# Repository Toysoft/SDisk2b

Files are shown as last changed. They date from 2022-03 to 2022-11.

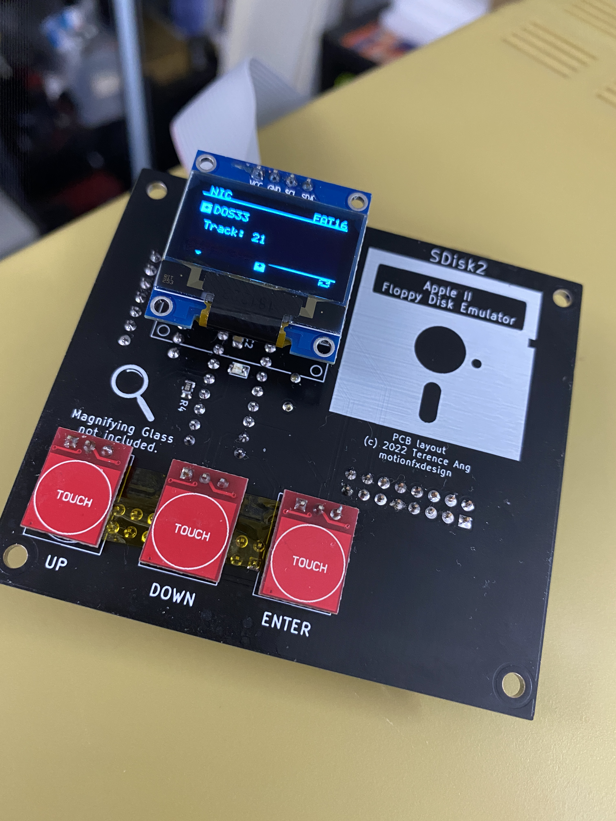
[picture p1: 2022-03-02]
PCB/SDisk2_Simple/Photos/20220302_010335090_iOS.jpg

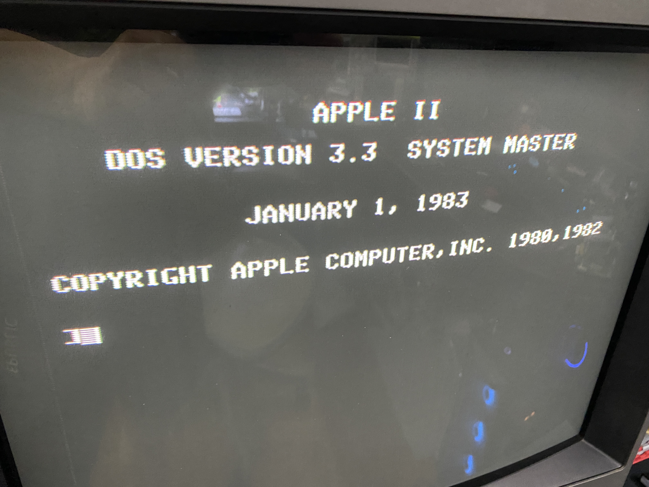
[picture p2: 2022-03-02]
PCB/SDisk2_Simple/Photos/20220302_010408004_iOS.jpg

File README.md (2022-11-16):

# SDisk2 - Simplified

Disk II flopy drive emulator for Apple 2 computers

Objective. an Open Source Disk II floppy Disk emulator that is easy to make.  
See readme in firmware and PCB section for related info.

## Changes

* 27Mhz Xtal.
* OLED only. All LCD and Nokia LCD codes have been removed.
* All Screen rotation code removed.
* Buttons re-arranged

## To-do

1. Better documentaion of the code.

This project will be migrated to an ESP32 based SDISKII.
<https://github.com/terenceang/sdisk2esp>

## Authors

* (c) 2010 Koichi NISHIDA <tulip-house@msf.biglobe.ne.jp>
* (c) 2012 Victor Trucco
* (c) 2012 Fábio Belavenuto
* (c) 2015 Alexandre Suaide
* (c) 2022 Terence Ang

## License

This work is released under the version 3 of the GNU General Public License.

'''NOTE:'''
The current legal status of this code is uncertain.

Fábio and Alexandre have published files with a header that references the version 3 of the GNU General Public License, but it is not clear yet what's the licensing chosen by the original author, Koichi Nishida.

This repository will be updated once the actual licensing info is clarified by the authors.

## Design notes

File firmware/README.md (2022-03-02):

# SDISKII - Simplied version

This package contains a new version of the firmware for the SDISKII with OLED and
buttons to select the NIC image.

Images are saved in the card in NIC format. You can convert DSK to NIC and NIC to DSK
using the utility provided by Nishida in his webpage

     http://tulip-house.ddo.jp/digital/SDISK2/english.html

You can organize your images in subdirectories and you can nest them in as many levels
as you want. In order to save your configuration and keep track of your last mounted
NIC image and directory you need to have the SDISKII.CFG file saved in the top directory
of your SD card. Please use the SDISKII.CFG file provided in this repository.

## FIRMWARE

Note. this fork only support the OLED version, for LCD and Nokia Version, please refer to orignial repo.

  This is for the second version of the SDISK II done by Victor Trucco already with the
  128 x 64 OLED graphical display and USB connection to update the firmware.

  Photos and schematics in the PCB section.

## Formatting the SD card

You can use this version of the firmware with standard SD cards as well as with SDHC
cards. You can format them in FAT16 or FAT32 only. The minimum cluster size is 32kB
(or 64 blocks per cluster). In order to formar a SD card, use the command:

### Windows: (use windows 7 or older. Windows 10 does not work)

    format [letter:] /FS:FAT /A:32K

*you can replace FAT by FAT32.*

### MAC OS/X

    diskutil partitionDisk /dev/[disk name] MBR FAT16 SDISKII 0b
    diskutil umountDisk /deve[disk name]
    newfs_msdos -F 16 -c 64 /dev/[disk name]

*you can replace 16 (FAT16) by 32 (FAT32). The same for the partition scheme.*   
*64 is the number of blocks per cluster and can be larger.*

### Linux

    mkfs.msdos -F 16 -s 64 /dev/[disk name]

*you can replace 16 (FAT16) by 32 (FAT32).*   
*64 is the number of blocks per cluster and can be larger.*

## Selecting NIC image

When there is no disk activity (LED off), press the middle button (ENTER). A list
of NIC files in the current directory as well as the subdirectories, will be created.
Navigate through the list using the LEFT and RIGHT buttons. Use the ENTER button to
select a NIC file or a directory. Directories are shown around [ ].

**Only NIC files are supported.**

## Selecting the delay of the SD card

Standard SD and SDHC cards can differ by a large value in terms of speed. In order
to compensate it a little bit the user can set the delay of the card from 1 (small delays)
to 10 (long delays). The default value is 5 and it looks fine for the cards I testes.
If you get a lot of problems reading NIC file, try to change it a little. I noticed
that ProDOS images are more sensitive to this setting than DOS 3.3 images.

When there is no disk activity (LED off), press the LEFT button. The SDISKII will
prompt you to select the speed of the card. Use the LEFT and RIGHT buttons to
navigate the available speeds and the ENTER (middle) button to select it.

## Swap between two disk images

If you have the SDISKII.CFG file saved in your SD card (see bellow) we keep track of the
previous mounted NIC image. In this case, if you press the RIGHT button we swap the current
mounted NIC with the previous one. This may be useful if you are copying from one image to
another or if you are playing a game that spans over two images.

## Saving the default values and last NIC mounted

In order to save your configurations (SD card speed and last NIC mounted) you need
to copy the file SDISKII.CFG (provided here) in the root directory of your SD card.
If this file is not present every time you turn on the SDISKII the first found NIC
will be mounted and the speed of the SD card will be set to 5.

## Upgrading your SDISKII with this new firmware

In order to upgrade your SDISKII with this new firmware you will need a chip programmer, such
as the MiniPro TL866CS. Remove the ATMEGA328P from your SDISKII, plug it in the programmer.
Open the programmer software, load the firmware.

Check if the fuses are right. The values for the fuses are:

    LFUSE = 0xF7
    HFUSE = 0xF9
    EFUSE = 0xFF

then program your ATMEGA328P with this new firmware. Put it back to the SDISKII and you are set.

*see customisation on how to roll your own version.*

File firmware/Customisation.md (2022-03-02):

# Customisation

## OLED Display - SSD1306

This firmware is made for SSD1306 IIC OLED, you can get them in 0.96 or 1.54 inches size.
pleasse take note of the pinout and make changes accordingly.
pinout configuration for this PCB.

1. VCC
2. GND
3. SCL - PC4
4. SDA - PC5

IIC address is 0x3C

The above can be changed in "config.h"

## SDCARD reader / writer

This PCB uses SDCard reader from LC Studio, this is an old prrt in my bin. It comes with a AM1117-3.3v on board.
You can use any SPI SDcard reader but you will need to convert 5v from the Disk interface to 3.3v for the rest of the circuit.

You will need to disable SD_EJECT signal if your SDcard reader don't support it.

Change
    #define SD_ejected()             bit_is_set(SD_PIN,SD_EJECT)
        to
    #define SD_ejected()             bit_is_clear(SD_PIN,SD_EJECT) // No SD_EJECT support

note. All VCC is 3.3v.

## Buttons

    Buttons
    Enter   - PD6
    Down    - PD7
    UP      - PB5

I am uaing TP223, button press is active high.
So button detection is.

    // Active high (using TP223)
    #define enter_is_pressed() bit_is_set(ENTER_PORT,ENTER_BIT)
    #define down_is_pressed()  bit_is_set(DOWN_PORT,DOWN_BIT)
    #define up_is_pressed()    bit_is_set(UP_PORT,UP_BIT)

Change bit_is_set to bit_is_celar for active low switches. e.g tact switch with pull up resistor.

## LED

    LED is on PB4

## Compiling the firmware

Use avr-gcc either on windows, mac or linux.
see avr-gcc website on how to set up the toolchain.

With the above info, you should be able to make your own SDISK2 version, please post your questions in the discussion page and I will try to help you with it. Thank you.

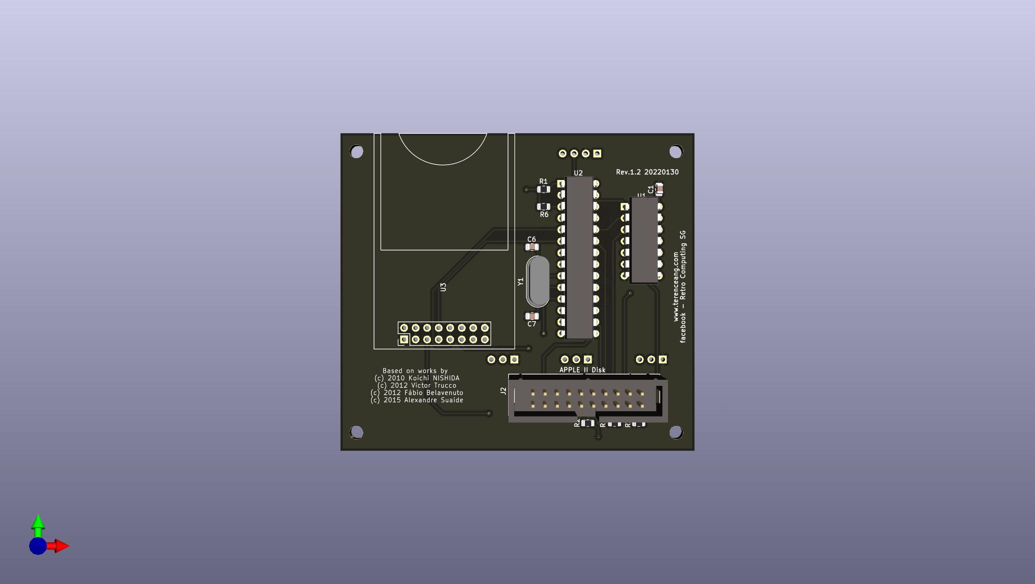
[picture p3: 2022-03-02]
PCB/SDisk2_Simple/Photos/SDisk2_Simple front.jpg

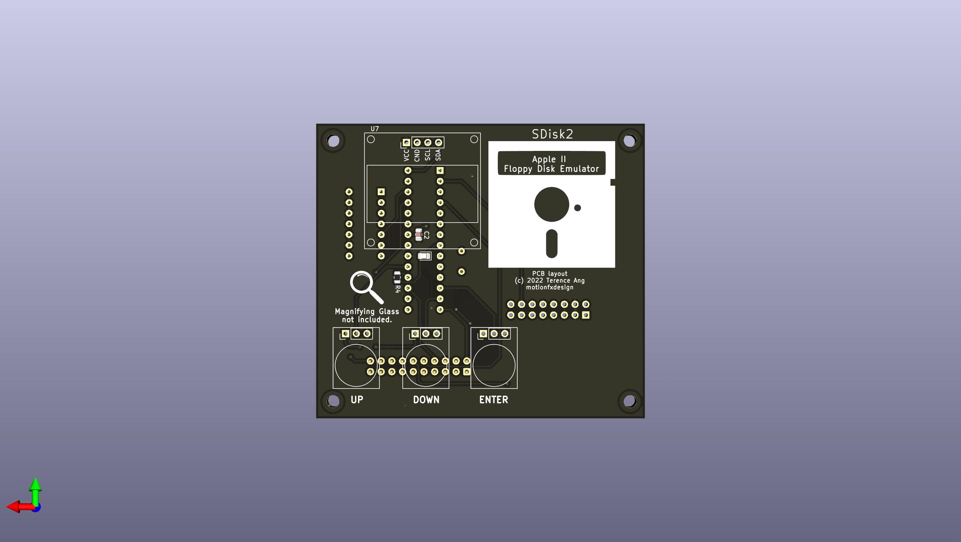
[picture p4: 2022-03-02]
PCB/SDisk2_Simple/Photos/SDisk2_Simple_back.jpg

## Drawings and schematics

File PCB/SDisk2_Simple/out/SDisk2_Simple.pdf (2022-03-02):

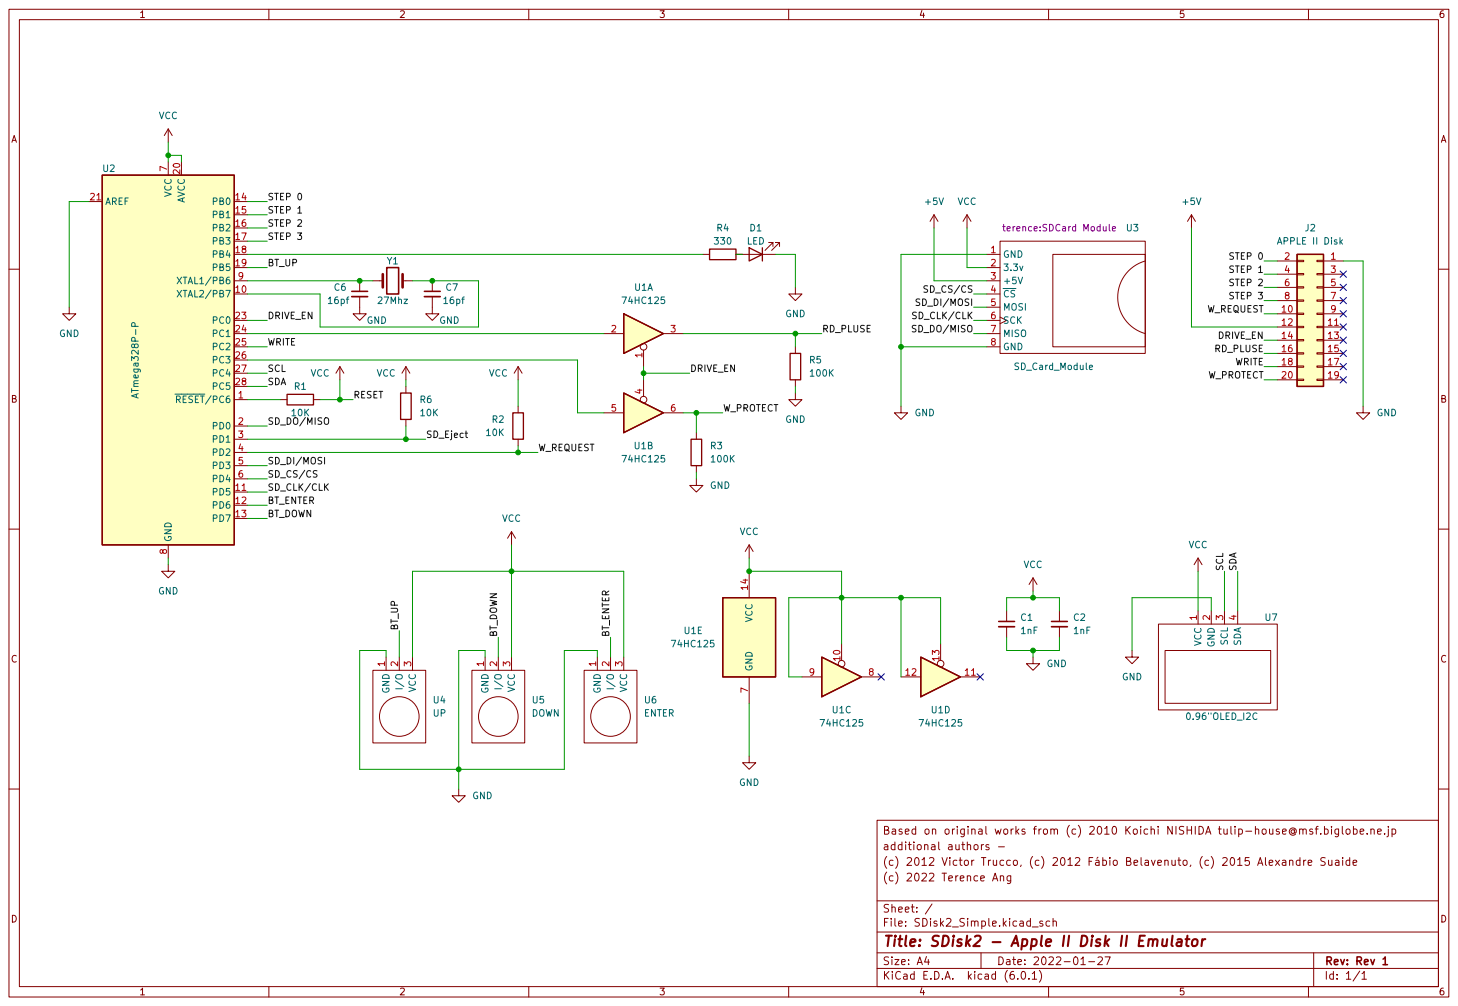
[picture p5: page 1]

J2 APPLE II Disk GND

additional authors - Based on original works from (c) 2010 Koichi NISHIDA tulip-house@msf.biglobe.ne.jp VCC 14 GND

3 U6 ENTER GND GND GND
74HC125 GND

File: SDisk2_Simple.kicad_sch Sheet: / (c) 2022 Terence Ang

Id: 1/1 Title: SDisk2 - Apple II Disk II Emulator

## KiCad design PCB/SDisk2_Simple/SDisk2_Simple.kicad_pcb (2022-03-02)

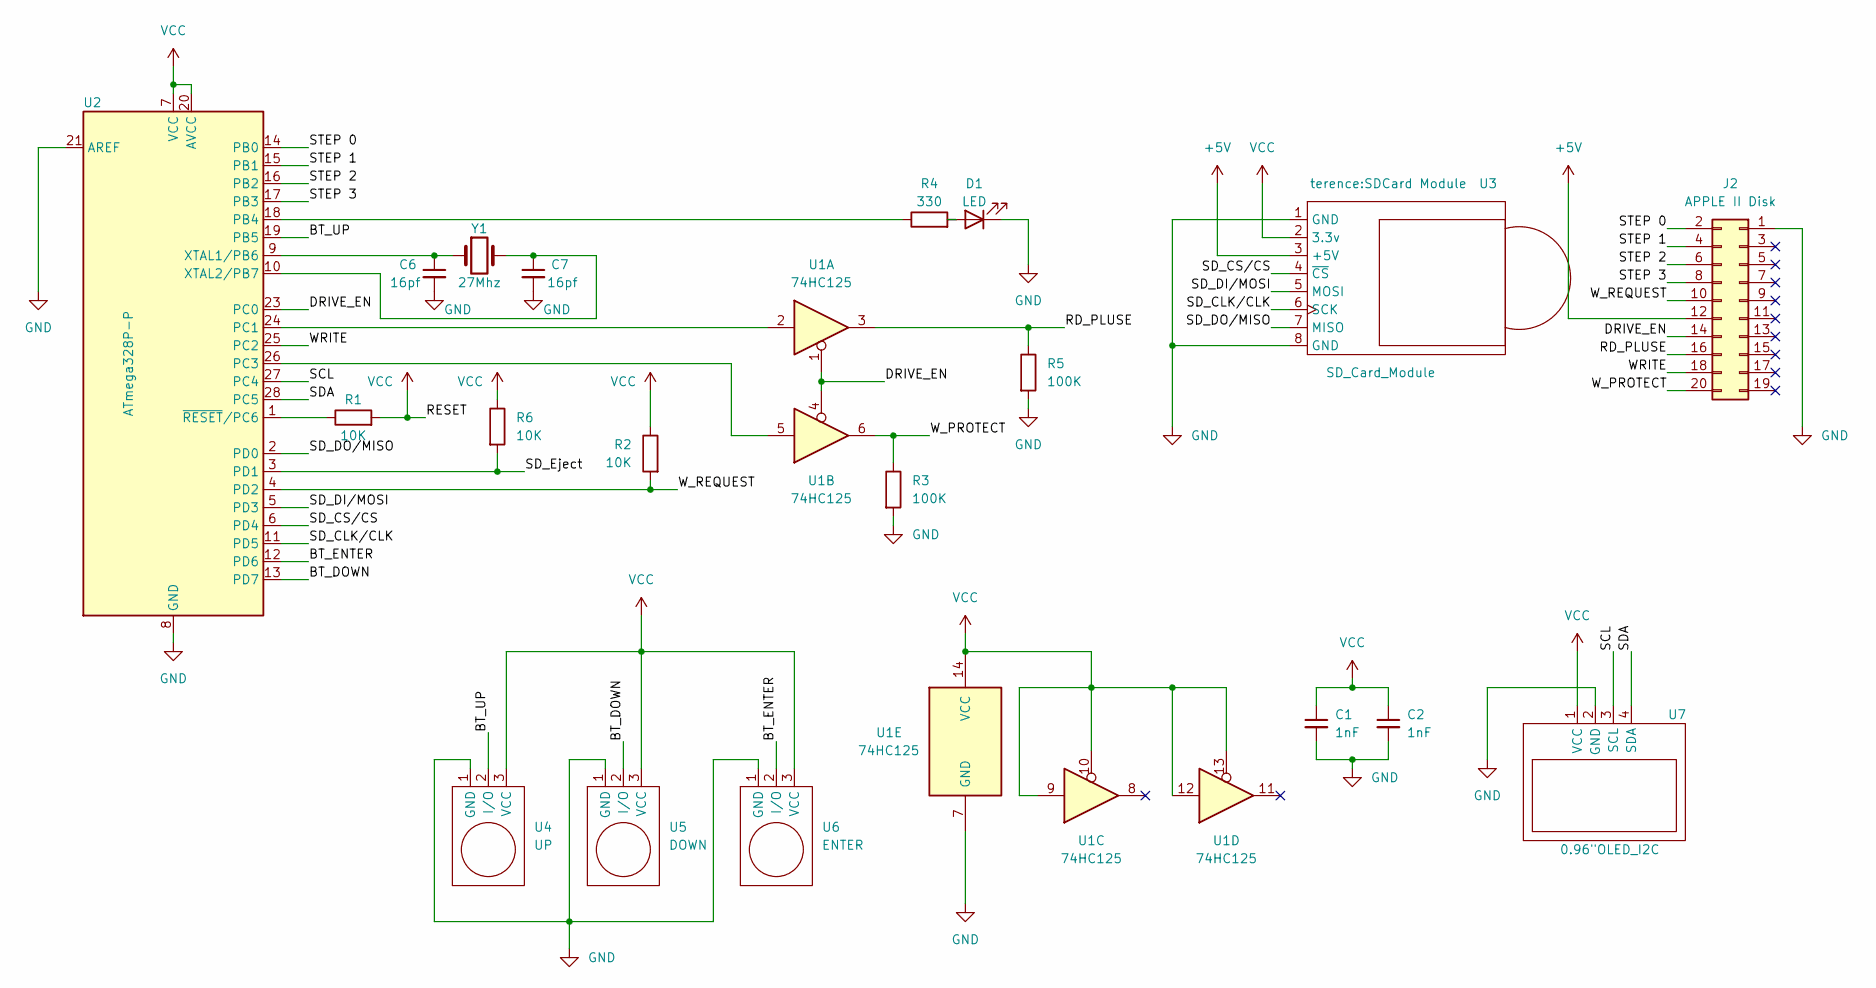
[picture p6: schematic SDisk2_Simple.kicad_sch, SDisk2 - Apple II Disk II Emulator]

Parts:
C1, C2: 1nF; C_0805_2012Metric
C6, C7: 16pf; C_0805_2012Metric
D1: LED; LED_0805_2012Metric
J2: APPLE II Disk; IDC-Header_2x10_P2.54mm_Vertical
R1, R2, R6: 10K; R_0805_2012Metric
R3, R5: 100K; R_0805_2012Metric
R4: 330; R_0805_2012Metric
U1: 74HC125; DIP-14_W7.62mm
U2: ATmega328P-P; DIP-28_W7.62mm
U3: SD_Card_Module; SDCard Module
U4: UP; TP223
U5: DOWN; TP223
U6: ENTER; TP223
U7: 0.96"OLED_I2C; 0.96OLED I2C
Y1: 27Mhz; Crystal_HC49-U_Vertical

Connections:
+5V: J2.12, U3.3 (+5V)
/BT_DOWN: U2.13 (PD7), U5.2 (I/O)
/BT_ENTER: U2.12 (PD6), U6.2 (I/O)
/BT_UP: U2.19 (PB5), U4.2 (I/O)
/DRIVE_EN: J2.14, U1.1, U1.4, U2.23 (PC0)
/RD_PLUSE: J2.16, R5.1, U1.3
/SCL: U2.27 (PC4), U7.3 (SCL)
/SDA: U2.28 (PC5), U7.4 (SDA)
/SD_CLK/CLK: U2.11 (PD5), U3.6 (SCK)
/SD_CS/CS: U2.6 (PD4), U3.4 (~CS)
/SD_DI/MOSI: U2.5 (PD3), U3.5 (MOSI)
/SD_DO/MISO: U2.2 (PD0), U3.7 (MISO)
/SD_Eject: R6.2, U2.3 (PD1)
/STEP 0: J2.2, U2.14 (PB0)
/STEP 1: J2.4, U2.15 (PB1)
/STEP 2: J2.6, U2.16 (PB2)
/STEP 3: J2.8, U2.17 (PB3)
/WRITE: J2.18, U2.25 (PC2)
/W_PROTECT: J2.20, R3.1, U1.6
/W_REQUEST: J2.10, R2.2, U2.4 (PD2)
GND: C1.2, C2.2, C6.2, C7.2, D1.1 (K), J2.1, R3.2, R5.2, U1.7 (GND), U2.8 (GND), U2.21 (AREF), U2.22 (GND), U3.1 (GND), U3.8 (GND), U4.1 (GND), U5.1 (GND), U6.1 (GND), U7.2 (GND)
unnamed: C6.1, U2.9 (XTAL1/PB6), Y1.1
unnamed: C7.1, U2.10 (XTAL2/PB7), Y1.2
unnamed: D1.2 (A), R4.2
unnamed: R1.1, U2.1 (~RESET/PC6)
unnamed: R4.1, U2.18 (PB4)
unnamed: U1.2, U2.24 (PC1)
unnamed: U1.5, U2.26 (PC3)
VCC: C1.1, C2.1, R1.2, R2.1, R6.1, U1.9, U1.10, U1.12, U1.13, U1.14 (VCC), U2.7 (VCC), U2.20 (AVCC), U3.2 (3.3v), U4.3 (VCC), U5.3 (VCC), U6.3 (VCC), U7.1 (VCC)

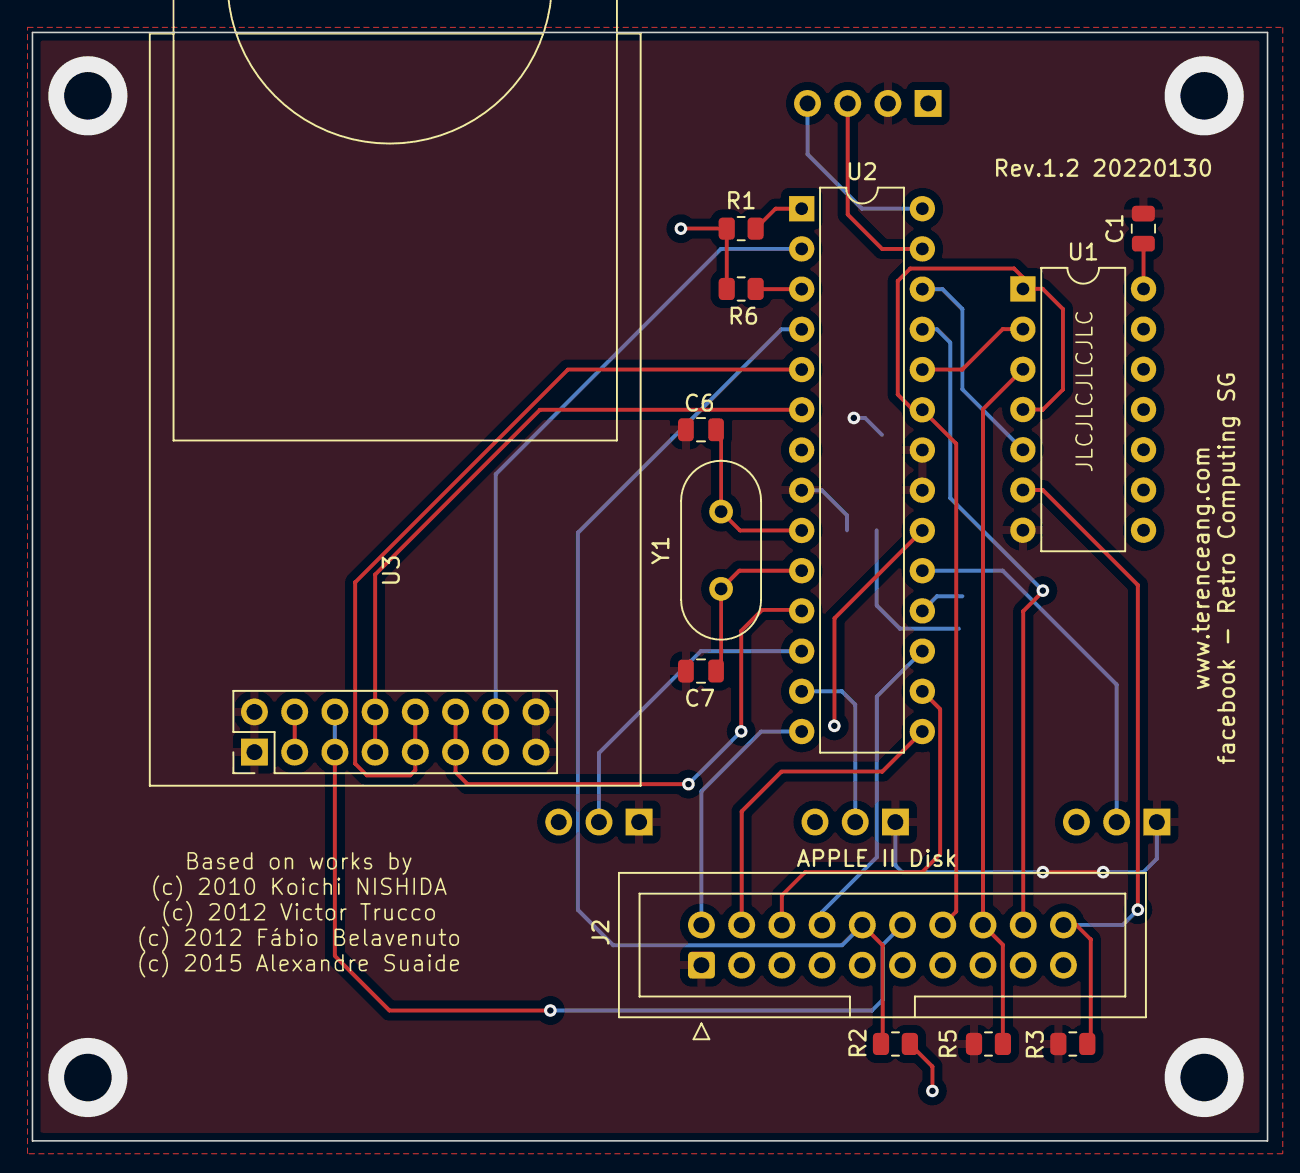
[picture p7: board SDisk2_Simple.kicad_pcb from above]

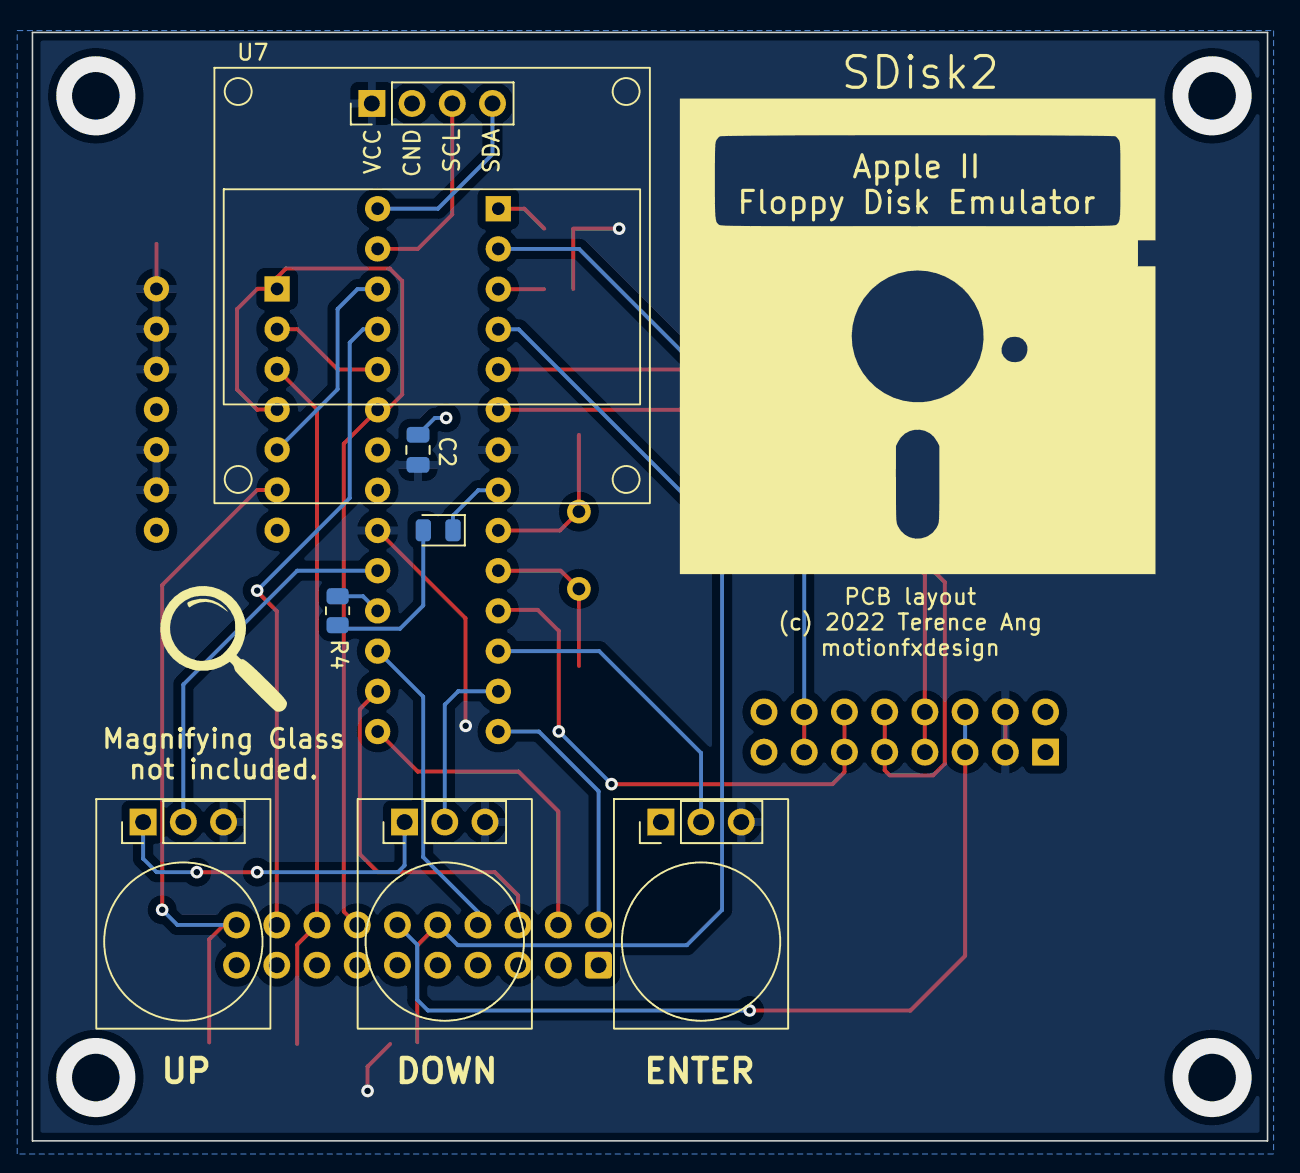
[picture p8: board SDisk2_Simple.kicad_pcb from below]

Board: 2 copper layers, 78.0 x 70.0 mm, 20 parts (7 on the bottom side), 29 nets.

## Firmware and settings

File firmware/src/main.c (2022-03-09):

/*------------------------------------
SDISK II LCD Firmware
2010.11.11 by Koichi Nishida
2012.01.26 by Fábio Belavenuto
2015.07.02 by Alexandre Suaide
-------------------------------------
*/

/*
2015.07.02 by Alexandre Suaide
Added support for SDHC cards and subdirectories
Removed DSK to NIC conversion
FAT16 and FAT32 disks should have at least 64 blocks per cluster
*/

/*
2012.01.26 by Fábio Belavenuto
Added support for image exchange using a button added in the Brazilian version by Victor Trucco
Added support for a 16x2 LCD
*/

/*
This is a part of the firmware for DISK II emulator by Nishida Radio.
Copyright (C) 2010 Koichi NISHIDA
email to Koichi NISHIDA: tulip-house@msf.biglobe.ne.jp
This program is free software; you can redistribute it and/or modify it
under the terms of the GNU General Public License as published by
the Free Software Foundation; either version 3 of the License.
This program is distributed in the hope that it will be useful,
but WITHOUT ANY WARRANTY; without even the implied warranty of
MERCHANTABILITY or FITNESS FOR A PARTICULAR PURPOSE.
See the GNU General Public License for more details.
You should have received a copy of the GNU General Public License
along with this program. If not, see <http://www.gnu.org/licenses/>.
*/

#include "main.h"

#define BUF_NUM 4 // originalmente era 5. testando por conta de um possivel overflow de memoria na sdisk nova com oled
unsigned char writeData[BUF_NUM][350];
unsigned char sectors[BUF_NUM], tracks[BUF_NUM];
unsigned char buffNum;
unsigned char *writePtr;
unsigned char flip_buttons;

#define DEBOUNCE 200

#define MAXFILES 200
unsigned char *files_id;
int nfiles = 0;
int selected_file_id = 0;
int id_of_config_file = -1;

#define FAT_NIC_ELEMS 10
#define NIC_FILE_SIZE 280
unsigned long fatNic[FAT_NIC_ELEMS];

// DISK II status
unsigned char ph_track; // 0 - 139
unsigned char sector;	// 0 - 15
unsigned short bitbyte; // 0 - (8*512-1)
unsigned char prepare;
unsigned char readPulse;
unsigned char inited;
unsigned char magState;
unsigned char protect;
unsigned char formatting;
const unsigned char volume = 0xfe;

unsigned char trk;
unsigned short long_sector;
unsigned short long_cluster;
unsigned long ft;
unsigned char old_trk;

/*Error codes
1 - Can not put SD Card on idle state
2 - Can not make SD Card initialization
3 - Can not init FAT
4 - Partition type not supported (only FAT16 and FAT32)
5 - Cluster size smaller than minimum to keep buffer
*/

/*                               012345678901234567890*/
PROGMEM const char SPLASH1[] = "      SDISK ][";
PROGMEM const char VERSION[] = "  version " VER " " YEAR;
PROGMEM const char NIC[] = " NIC                 ";
PROGMEM const char SETUP[] = " SETUP               ";
PROGMEM const char EMP[] = "                     ";
PROGMEM const char SET1[] = " Set SD delay        ";
PROGMEM const char SET2[] = " Set contrast        ";
PROGMEM const char SET3[] = " Rotate display      ";
PROGMEM const char VALUE[] = " Value: ";
PROGMEM const char CONT[] = " LCD CONTRAST        ";
PROGMEM const char DLAY[] = " SD SELECT DELAY     ";
PROGMEM const char TRAK[] = "Track: ";
PROGMEM const char MSG7[] = " SELECT NIC          ";
PROGMEM const char MSGC[] = " Building list";
PROGMEM const char MSG8[] = " Nothing found here! ";
PROGMEM const char MSGD[] = " Sorting files ...   ";
PROGMEM const char MSHC[] = "SDHC card     ";
PROGMEM const char MSSD[] = "Normal SD card";
PROGMEM const char ERR[] = "E R R O R";
PROGMEM const char ERM1[] = "SD can't idle ";
PROGMEM const char ERM2[] = "SD can't init ";
PROGMEM const char ERM3[] = "Boot sector   ";
PROGMEM const char ERM4[] = "Not FAT16/32  ";
PROGMEM const char ERM5[] = "Cluster < 32kB";
PROGMEM const char ERM6[] = "Missing MBR   ";
PROGMEM const char ERM7[] = "SD Block ERROR";
PROGMEM const char ERMC[] = "Code: ";
PROGMEM const char PART[] = "Type: ";
PROGMEM const char FAT3[] = "FAT32";
PROGMEM const char FAT1[] = "FAT16";
PROGMEM const char SDOUT[] = "No SD inserted";
#define TRX 12
#define TRY 4

PROGMEM const char CFG[] = "SDISKII CFG";

// a table for head stepper motor movement
PROGMEM const prog_uchar stepper_table[4] = {0x0f, 0xed, 0x03, 0x21};

int main(void)
{
	static unsigned char oldStp = 0, stp;
	init(1);
	old_trk = 255;
	while (1)
	{
		verify_status();
		if (diskII_disable())
		{
			SD_led_off();
		}
		else
		{
			SD_led_on();
			stp = (PINB & 0b00001111);
			if (stp != oldStp)
			{
				oldStp = stp;
				unsigned char ofs = ((stp == 0b00001000) ? 2 : ((stp == 0b00000100) ? 4 : ((stp == 0b00000010) ? 6 : ((stp == 0b00000001) ? 0 : 0xff))));
				if (ofs != 0xff)
				{
					ofs = ((ofs + ph_track) & 7);
					unsigned char bt = pgm_read_byte_near(stepper_table + (ofs >> 1));
					oldStp = stp;
					if (ofs & 1)
						bt &= 0x0f;
					else
						bt >>= 4;
					ph_track += ((bt & 0x08) ? (0xf8 | bt) : bt);
					if (ph_track > 196)
						ph_track = 0;
					if (ph_track > 139)
						ph_track = 139;
				}
			}

			if (inited && prepare)
			{
				cli();
				sector = ((sector + 1) & 0xf);
				{
					trk = (ph_track >> 2);
					long_sector = (unsigned short)trk * 16 + sector;
					long_cluster = long_sector >> FAT_sectorsPerClusterBitShift;
					ft = fatNic[long_cluster];
					if (trk != old_trk)
					{
						old_trk = trk;
						ssd1306_gotoxy(TRX, TRY);
						ssd1306_put_p(TRAK);
						if (trk < 10)
							ssd1306_string(" ");
						ssd1306_put_i((unsigned int)trk);
					}

					if (((sectors[0] == sector) && (tracks[0] == trk)) || ((sectors[1] == sector) && (tracks[1] == trk)) ||
						((sectors[2] == sector) && (tracks[2] == trk)) || ((sectors[3] == sector) && (tracks[3] == trk)))
						writeBackSub();

					// Timing is an issue here. This is the reason I copied explicitly the conversion from cluster to block
					// instead of using getCluster() method. I also did bit shift instead of multiplications to make it faster.
					// even inline function is not fast enough.
					// SD_CMD17Special is also faster than the regular SD_sendCommand method.
					SD_CMD17Special((((ft - 2) << FAT_sectorsPerClusterBitShift) + FAT_firstDataSector) + (long_sector & (FAT_sectorsPerCluster - 1)));
					bitbyte = 0;
					prepare = 0;
				}

				sei();
			}
		}
	}
}

void display_sd_ejected()
{

	ssd1306_clear();
	ssd1306_gotoxy(37, 2);
	ssd1306_put_p(ERR);
	ssd1306_gotoxy(22, 4);
	ssd1306_put_p(SDOUT);

	do
	{
	} while (SD_ejected());
	return;
}

char init_sd(char splash)
{
	id_of_config_file = -1;
	SPI_slow();
	SD_select_card();
	unsigned char ok;
	if (SD_ejected())
	{
		display_sd_ejected();
		return 0;
	}

	buffer = &writeData[0][0];
	ok = SD_init();

	if (!ok)
	{
		ssd1306_clear();
		ssd1306_gotoxy(37, 2);
		ssd1306_put_p(ERR);
		ssd1306_gotoxy(22, 4);
		if (errorCode == 1)
			ssd1306_put_p(ERM1);
		else if (errorCode == 2)
			ssd1306_put_p(ERM2);
		else if (errorCode == 3)
			ssd1306_put_p(ERM3);
		else if (errorCode == 4)
			ssd1306_put_p(ERM4);
		else if (errorCode == 5)
			ssd1306_put_p(ERM5);
		else if (errorCode == 6)
			ssd1306_put_p(ERM6);
		else if (errorCode == 7)
			ssd1306_put_p(ERM7);
		else
		{
			ssd1306_put_p(ERMC);
			ssd1306_put_i(errorCode);
		}
		inited = 0;
		while (!SD_ejected())
		{
		};
		return 0;
	}

	if (splash)
	{
		ssd1306_clear();
		ssd1306_gotoxy(0, 2);

		if (SD_version == SD_RAW_SPEC_SDHC)
			ssd1306_put_p(MSHC);
		else
			ssd1306_put_p(MSSD);

		SD_select_card();
		_delay_ms(1000);
	}

	ok = FAT_init();
	if (!ok)
	{
		ssd1306_clear();
		ssd1306_gotoxy(37, 2);
		ssd1306_put_p(ERR);
		ssd1306_gotoxy(22, 4);

		if (errorCode == 1)
			ssd1306_put_p(ERM1);
		else if (errorCode == 2)
			ssd1306_put_p(ERM2);
		else if (errorCode == 3)
			ssd1306_put_p(ERM3);
		else if (errorCode == 4)
			ssd1306_put_p(ERM4);
		else if (errorCode == 5)
			ssd1306_put_p(ERM5);
		else if (errorCode == 6)
			ssd1306_put_p(ERM6);
		else if (errorCode == 7)
			ssd1306_put_p(ERM7);
		else
		{
			ssd1306_put_p(ERMC);
			ssd1306_put_i(errorCode);
		}
		inited = 0;
		while (!SD_ejected())
		{
		};
		return 0;
	}

	if ((FAT_bytesPerSector * FAT_sectorsPerCluster / 1024) < (NIC_FILE_SIZE / FAT_NIC_ELEMS))
	{
		errorCode = 5;
		ssd1306_clear();
		ssd1306_gotoxy(37, 2);
		ssd1306_put_p(ERR);
		ssd1306_gotoxy(22, 4);
		ssd1306_put_p(ERM5);

		inited = 0;
		while (!SD_ejected())
		{
		};
		return 0;
	}

	if (splash)
	{
		ssd1306_gotoxy(0, 4);

		ssd1306_put_p(PART);
		if (FAT_partitionType == PARTITION_TYPE_FAT16)
			ssd1306_put_p(FAT1);
		else
			ssd1306_put_p(FAT3);

		_delay_ms(1000);
		// SD_select_card();
	}
	SD_select_card();
	buffClear();
	SPI_fast();
	return 1;
}

void init(char splash)
{
	// configuracao das portas do microcontrolador

	DDRB = 0;
	DDRC = 0;
	DDRD = 0;

	PORTB = 0;
	PORTC = 0;
	PORTD = 0;

	// configuração do LED
	set_bit(SD_LED_PORTD, SD_LED);
	set_bit(SD_LED_PORT, SD_LED); // LED ligado

	// configuração da interface com o Apple
	set_bit(DDRC, 1);
	set_bit(DDRC, 3);
	set_bit(PORTC, 1);

	// configuração da interrupção de tempo
	OCR0A = 0;
	TCCR0A = 0;
	TCCR0B = 1;

	// configuração da interrupção int0
	MCUCR = 0b00000010;
	EICRA = 0b00000010;

	sector = 0;
	inited = 0;
	readPulse = 0;
	protect = 0;
	bitbyte = 0;
	magState = 0;
	prepare = 1;
	ph_track = 0;
	buffNum = 0;
	formatting = 0;
	writePtr = &(writeData[buffNum][0]);

	if (splash)
	{
		ssd1306_init();
		ssd1306_clear();
		ssd1306_gotoxy(0, 0);
		logo();
		ssd1306_gotoxy(13, 6);
		ssd1306_put_p(SPLASH1);
		ssd1306_gotoxy(7, 7);
		ssd1306_put_p(VERSION);
		_delay_ms(1500);
	}
}

void verify_status(void)
{
	unsigned int i;
	configButtons();
	if (SD_ejected())
	{
		for (i = 0; i != 0xFF; i++)
			if (!SD_ejected())
				return;
		TIMSK0 &= ~(1 << TOIE0);
		EIMSK &= ~(1 << INT0);
		inited = 0;
		prepare = 0;
		display_sd_ejected();
		return;
	}
	else if (diskII_disable() && (enter_is_pressed() || down_is_pressed() || up_is_pressed()))
	{
		if (enter_is_pressed()) // drive disabled
		{
			unsigned char flg = 1;
			for (i = 0; i != 100; i++)
				if (!enter_is_pressed())
					flg = 0;
			if (flg)
			{
				while (enter_is_pressed())
					; // enter button pushed !
				cli();
				select_nic();
				if (SD_ejected())
					return;
				if (inited)
				{
					TIMSK0 |= (1 << TOIE0);
					EIMSK |= (1 << INT0);
				}
				sei();
			}
			return;
		}

		else if (down_is_pressed()) // setup
		{
			unsigned char flg = 1;
			for (i = 0; i != 100; i++)
				if (!down_is_pressed())
					flg = 0;
			if (flg)
			{
				while (down_is_pressed())
					; // enter button pushed !
				cli();
				setup();
				if (SD_ejected())
					return;
				find_previous_nic();
				if (inited)
				{
					TIMSK0 |= (1 << TOIE0);
					EIMSK |= (1 << INT0);
				}
				sei();
			}
			return;
		}
		else if (up_is_pressed())
		{
			unsigned char flg = 1;
			for (i = 0; i != 100; i++)
				if (!up_is_pressed())
					flg = 0;
			if (flg)
			{
				while (up_is_pressed())
					; // botao ainda apertado
				cli();
				swap_nic();
				if (SD_ejected())
					return;
				if (inited)
				{
					TIMSK0 |= (1 << TOIE0);
					EIMSK |= (1 << INT0);
				}
				sei();
			}
		}
	}
	else if (!inited) // if not initialized
	{
		for (i = 0; i != 0xFF; i++)
			if (SD_ejected())
				return;
		cli();
		if (init_sd(1))
			find_previous_nic();
		if (inited)
		{

			TIMSK0 |= (1 << TOIE0);
			EIMSK |= (1 << INT0);
		}
		sei();
	}
}

// Contrast Page
void set_contrast()
{
	unsigned char contrast = 0XAF;
	if (id_of_config_file != -1)
	{
		cd(0);
		buffer = &writeData[0][0];
		buffClear();
		lastBlockRead = 0;
		struct dir_Structure *config_file = getFile(id_of_config_file);
		unsigned long cluster;

		if (FAT_partitionType == PARTITION_TYPE_FAT32)
			cluster = (unsigned long)config_file->firstClusterHI << 16 | (unsigned long)config_file->firstClusterLO;
		else
			cluster = (unsigned long)config_file->firstClusterLO;

		SD_readSingleBlock(getSector(cluster));
		struct Sdisk_config_structure *config = (struct Sdisk_config_structure *)buffer;
		if (config->checksum == CHECKSUM_CONFIG)
		{
			contrast = config->oled_contrast;
		}
	}
	ssd1306_clear();
	ssd1306_gotoxy(0, 0);
	ssd1306_underline();
	ssd1306_put_p(CONT);
	ssd1306_underline();
	icons(3, 4, 5); // 5-enter, 4-down, 3-up

	ssd1306_gotoxy(0, 2);
	ssd1306_put_p(VALUE);
	ssd1306_put_i(contrast);

	unsigned char old_contrast = contrast;
	unsigned char original_contrast = contrast;
	while (1)
	{
		configButtons();
		if (contrast != old_contrast)
		{
			ssd1306_gotoxy(0, 2);
			ssd1306_put_p(VALUE);
			ssd1306_put_i(contrast);
			ssd1306_put_p(PSTR(" "));
			old_contrast = contrast;
		}

		if (SD_ejected())
			return; // card is removed
		if (down_is_pressed())
		{
			while (down_is_pressed())
			{
			}
			_delay_ms(DEBOUNCE);

			contrast--;
			if (contrast < MIN_CONTRAST)
				contrast = MIN_CONTRAST;
			else
			{
				oled_contrast = contrast;
				ssd1306_contrast(oled_contrast);
			}
		}
		if (up_is_pressed())
		{
			while (up_is_pressed())
			{
			}
			_delay_ms(DEBOUNCE);

			contrast++;
			if (contrast > MAX_CONTRAST)
				contrast = MAX_CONTRAST;
			else
			{
				oled_contrast = contrast;
				ssd1306_contrast(oled_contrast);
			}
		}
		if (enter_is_pressed())
		{
			while (enter_is_pressed())
			{
			}
			_delay_ms(DEBOUNCE);
			if (contrast != original_contrast)
			{
				oled_contrast = contrast;
				ssd1306_contrast(oled_contrast);
				SD_select_card();
				if (id_of_config_file != -1)
				{
					cd(0);
					buffer = &writeData[0][0];
					buffClear();
					lastBlockRead = 0;
					struct dir_Structure *config_file = getFile(id_of_config_file);
					unsigned long cluster;

					if (FAT_partitionType == PARTITION_TYPE_FAT32)
						cluster = (unsigned long)config_file->firstClusterHI << 16 | (unsigned long)config_file->firstClusterLO;
					else
						cluster = (unsigned long)config_file->firstClusterLO;

					SD_readSingleBlock(getSector(cluster));
					struct Sdisk_config_structure *config = (struct Sdisk_config_structure *)buffer;
					if (config->checksum == CHECKSUM_CONFIG)
					{
						config->oled_contrast = contrast;
						SD_writeSingleBlock(getSector(cluster));
					}
				}
			}
			return;
		}
	}
	return;
}

// Setup Page
void setup()
{
	ssd1306_clear();
	ssd1306_gotoxy(0, 0);
	ssd1306_underline();
	ssd1306_put_p(SETUP);
	ssd1306_underline();

	icons(3, 4, 5); // 5-enter, 4-down, 3-up

	unsigned char option = 1;
	ssd1306_gotoxy(0, 2);
	ssd1306_inverse();
	ssd1306_put_p(SET1); // set speed
	ssd1306_inverse();
	ssd1306_gotoxy(0, 3);
	ssd1306_put_p(SET2); // set contrast

#define MAX_SET 2 // number of item

	while (1)
	{
		configButtons();
		if (down_is_pressed())
		{
			while (down_is_pressed())
			{
			}
			_delay_ms(DEBOUNCE);

			option++;
			if (option > MAX_SET)
				option = MAX_SET;
			else
			{
				if (option == 1)
					ssd1306_inverse();
				ssd1306_gotoxy(0, 2);
				ssd1306_put_p(SET1);
				if (option == 1)
					ssd1306_inverse();

				if (option == 2)
					ssd1306_inverse();
				ssd1306_gotoxy(0, 3);
				ssd1306_put_p(SET2);
				if (option == 2)
					ssd1306_inverse();
			}
		}
		if (up_is_pressed())
		{
			while (up_is_pressed())
			{
			}
			_delay_ms(DEBOUNCE);

			option--;
			if (option < 1)
				option = 1;
			else
			{
				if (option == 1)
					ssd1306_inverse();
				ssd1306_gotoxy(0, 2);
				ssd1306_put_p(SET1);
				if (option == 1)
					ssd1306_inverse();

				if (option == 2)
					ssd1306_inverse();
				ssd1306_gotoxy(0, 3);
				ssd1306_put_p(SET2);
				if (option == 2)
					ssd1306_inverse();
			}
		}
		if (enter_is_pressed())
		{
			while (enter_is_pressed())
			{
			}
			_delay_ms(DEBOUNCE);
			if (option == 1)
				set_speed();
			if (option == 2)
				set_contrast();
			return;
		}
	}
}

void icons(unsigned char i1, unsigned char i2, unsigned char i3)
{

#define IC_LINE 7
#define IC_1 0
#define IC_2 58
#define IC_3 115

	ssd1306_gotoxy(IC_1, IC_LINE);
	ssd1306_overline();
	ssd1306_put_p(EMP);
	ssd1306_gotoxy(IC_1, IC_LINE);
	ssd1306_icon(i1);
	ssd1306_gotoxy(IC_2, IC_LINE);
	ssd1306_icon(i2);
	ssd1306_gotoxy(IC_3, IC_LINE);
	ssd1306_icon(i3);
	ssd1306_overline();
}

void set_speed()
{
	ssd1306_clear();
	ssd1306_gotoxy(0, 0);
	ssd1306_underline();
	ssd1306_put_p(DLAY);
	ssd1306_underline();
	icons(3, 5, 4); // 5-setup, 4-Disk, 3-last Disk
	ssd1306_gotoxy(0, 3);
	ssd1306_put_p(VALUE);
	ssd1306_put_i(SD_speed);

	unsigned char old_speed = SD_speed;
	unsigned char original_speed = SD_speed;
	while (1)
	{
		configButtons();
		if (SD_speed != old_speed)
		{

			ssd1306_gotoxy(0, 3);
			ssd1306_put_p(VALUE);
			ssd1306_put_i(SD_speed);
			ssd1306_put_p(PSTR(" "));
			old_speed = SD_speed;
		}

		if (SD_ejected())
			return; // card is removed
		if (down_is_pressed())
		{
			while (down_is_pressed())
			{
			}
			_delay_ms(DEBOUNCE);

			SD_speed--;
			if (SD_speed < SD_MIN_SPEED)
				SD_speed = SD_MAX_SPEED;
		}
		if (up_is_pressed())
		{
			while (up_is_pressed())
			{
			}
			_delay_ms(DEBOUNCE);

			SD_speed++;
			if (SD_speed > SD_MAX_SPEED)
				SD_speed = SD_MIN_SPEED;
		}
		if (enter_is_pressed())
		{
			while (enter_is_pressed())
			{
			}
			_delay_ms(DEBOUNCE);
			if (SD_speed != original_speed)
			{
				if (id_of_config_file != -1)
				{
					cd(0);
					buffer = &writeData[0][0];
					buffClear();
					lastBlockRead = 0;
					struct dir_Structure *config_file = getFile(id_of_config_file);
					unsigned long cluster;

					if (FAT_partitionType == PARTITION_TYPE_FAT32)
						cluster = (unsigned long)config_file->firstClusterHI << 16 | (unsigned long)config_file->firstClusterLO;
					else
						cluster = (unsigned long)config_file->firstClusterLO;

					SD_readSingleBlock(getSector(cluster));
					struct Sdisk_config_structure *config = (struct Sdisk_config_structure *)buffer;
					if (config->checksum == CHECKSUM_CONFIG)
					{
						config->sd_card_speed = SD_speed;
						SD_writeSingleBlock(getSector(cluster));
					}
				}
			}
			return;
		}
	}
	return;
}

// Nic Selection Page
void select_nic()
{
	int i = 0, j = 0, k = 0;
	char name1[8];
	nfiles = 0;
	buffer = &writeData[0][0];
	files_id = &writeData[2][0];
	lastBlockRead = -1;
	buffClear();

	ssd1306_underline();
	ssd1306_gotoxy(0, 0);
	ssd1306_put_p(MSG7);
	ssd1306_underline();
	icons(3, 4, 5); // 3-up, 4-down, 5-enter
	for (i = 1; i <= 5; i++)
	{
		ssd1306_gotoxy(0, i);
		ssd1306_put_p(EMP);
	}
	ssd1306_gotoxy(0, 3);
	ssd1306_put_p(MSGC);

	i = 0;

	do
	{
		struct dir_Structure *file = getFile(i);
		if (file)
			if (file->name[0] == 0x00)
				break; // last file on directory
		if (is_a_nic(file) || is_a_dir(file))
		{
			files_id[nfiles] = i;
			nfiles++;
		}
		i++;
	} while (nfiles < MAXFILES && i < MAXFILES * 2);

	if (nfiles == 0)
	{
		ssd1306_gotoxy(0, 3);
		ssd1306_put_p(MSG8);
		return;
	}

	ssd1306_gotoxy(0, 3);
	ssd1306_put_p(MSGD);

	// sort list of files in the directory
	if (nfiles > 1)
	{
		for (i = 0; i <= (nfiles - 2); i++)
		{
			for (j = 1; j <= (nfiles - i - 1); j++)
			{
				struct dir_Structure *file1 = getFile(files_id[j]);
				strlcpy(name1, (const char *)file1->name, 8);
				struct dir_Structure *file2 = getFile(files_id[j - 1]);
				if (memcmp(name1, file2->name, 8) < 0)
				{
					k = files_id[j];
					files_id[j] = files_id[j - 1];
					files_id[j - 1] = k;
				}
			}
		}
	}

	int index = 0;
	for (i = 0; i < nfiles; i++)
		if (selected_file_id == files_id[i])
			index = i;
	int index_old = -1;
	while (1)
	{
		configButtons();
		if (SD_ejected())
			return; // card is removed
		if (down_is_pressed())
		{
			while (down_is_pressed())
			{
			}
			_delay_ms(DEBOUNCE);

			index++;
			if (index == nfiles)
				index = 0;
		}
		if (up_is_pressed())
		{
			while (up_is_pressed())
			{
			}
			_delay_ms(DEBOUNCE);

			index--;
			if (index < 0)
				index = nfiles - 1;
		}
		if (enter_is_pressed())
		{
			while (enter_is_pressed())
			{
			}
			_delay_ms(DEBOUNCE);
			struct dir_Structure *file = getFile(files_id[index]);
			if (is_a_dir(file))
			{
				cd(file);
				select_nic();
				return;
			}
			else
			{
				mount_nic_image(files_id[index], file);
				return;
			}
			return;
		}
		if (index != index_old)
		{
			index_old = index;
			struct dir_Structure *file = getFile(files_id[index]);

			ssd1306_gotoxy(0, 3);
			if (is_a_dir(file))
				ssd1306_icon(6);
			else
				ssd1306_icon(1);
			unsigned char count = 0;
			for (int i = 0; i < 8; i++)
				if (file->name[i] != ' ')
				{
					ssd1306_char(file->name[i]);
					count++;
				}
			for (int i = count; i < 16; i++)
				ssd1306_char(' ');
		}
	}
}
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

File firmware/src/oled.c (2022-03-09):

#include "oled.h"
#include "charset.h"
#include "logo.h"
#include "i2c.h"
#include <stdlib.h>
#include "string.h"

#define false 0
#define true  1

unsigned char ssd1306_contr;
unsigned char ssd1306_inv;
unsigned char ssd1306_under;
unsigned char ssd1306_over;

void  ssd1306_command(int c)
{
    int control = 0x00; // some use 0X00 other examples use 0X80. I tried both 
    i2c_start((SSD1306_ADDRESS<<1) | I2C_WRITE);
    i2c_write(control); // This is Command
    i2c_write(c);
    i2c_stop();
}

void  ssd1306_data(unsigned char c)
{
    i2c_start((SSD1306_ADDRESS<<1) | I2C_WRITE);
    i2c_write(0X40); // This byte is DATA
    i2c_write(c);
    i2c_stop();
}


void ssd1306_contrast(unsigned char value)
{
    ssd1306_command(SSD1306_SETCONTRAST);                   // 0x81
    ssd1306_command(value);
    ssd1306_contr = value;
}

void ssd1306_init()
{
    i2c_init();
    ssd1306_command(SSD1306_DISPLAYOFF);                    // 0xAE  
	  ssd1306_command(SSD1306_NORMALDISPLAY); 
    ssd1306_command(SSD1306_SETDISPLAYCLOCKDIV);            // 0xD5
    ssd1306_command(0x80);                                  // the suggested ratio 0x80   
    ssd1306_command(SSD1306_SETMULTIPLEX);                  // 0xA8    
	  ssd1306_command(0x3F); 
    ssd1306_command(SSD1306_SETDISPLAYOFFSET);              // 0xD3
    ssd1306_command(0x0);                                   // no offset  
    ssd1306_command(SSD1306_SETSTARTLINE | 0x0);            // line #0   
    ssd1306_command(SSD1306_CHARGEPUMP);                    // 0x8D
    ssd1306_command(0x14);                                  // using internal VCC 
    ssd1306_command(SSD1306_MEMORYMODE);                    // 0x20
    ssd1306_command(0x00);                                  // 0x00 horizontal addressing  
    ssd1306_command(SSD1306_SEGREMAP);                     // rotate screen 180 
    ssd1306_command(SSD1306_COMSCANDEC);                    // rotate screen 180  
	
    ssd1306_command(SSD1306_SETCOMPINS);                    // 0xDA
    ssd1306_command(0x12);  
    ssd1306_command(SSD1306_SETCONTRAST);                   // 0x81
    ssd1306_command(0xCF);  
    ssd1306_command(SSD1306_SETPRECHARGE);                  // 0xd9
    ssd1306_command(0xF1);  
    ssd1306_command(SSD1306_SETVCOMDETECT);                 // 0xDB
    ssd1306_command(0x40);  
    ssd1306_command(SSD1306_DISPLAYALLON_RESUME);           // 0xA4  
    ssd1306_command(SSD1306_NORMALDISPLAY);                 // 0xA6
    ssd1306_command(SSD1306_DISPLAYON);                     //switch on OLED
    ssd1306_contr = 0xCF;
    oled_contrast = ssd1306_contr;
	  ssd1306_offset = 2;
    ssd1306_inv = 0;
    ssd1306_under = 0;
    ssd1306_over = 0;
	  ssd1306_screenUp();
}

void ssd1306_clear()
{
  for(int line = 0 ; line<8; line++)
  {
	  ssd1306_gotoxy(0,line);
	  for(int col = 0; col<132; col++) ssd1306_data(0);
  }
  i2c_stop(); 
}

void ssd1306_char(unsigned char c)
{
  i2c_start((SSD1306_ADDRESS<<1) | I2C_WRITE);
  i2c_write(0X40);
  
  for (int index = 0; index < 5; index++)
  {
    unsigned char ascii = (unsigned char)pgm_read_byte(&ASCII[c - 0x20][index]);
    if(ssd1306_inv) ascii = 255-ascii;
    ascii = ascii | (1<<7)*(ssd1306_under==true) | (ssd1306_over==true);
    
    i2c_write(ascii);
  }
  i2c_write(255*(ssd1306_inv==true) | (1<<7)*(ssd1306_under==true) | (ssd1306_over==true));
  i2c_stop();
}
void ssd1306_string(char *string)
{
  while (*string)
  {
    ssd1306_char(*string++);
  }
}

void ssd1306_screenUp()
{
    ssd1306_command(SSD1306_SEGREMAP | 0x1);                
    ssd1306_command(SSD1306_COMSCANDEC);                   
    ssd1306_clear();
}

void ssd1306_screenDown()
{
    ssd1306_command(SSD1306_SEGREMAP | 0x0);                
    ssd1306_command(SSD1306_COMSCANINC);
    ssd1306_clear();
}

void ssd1306_inverse() {ssd1306_inv=!ssd1306_inv;}
void ssd1306_underline() {ssd1306_under=!ssd1306_under;}
void ssd1306_overline() {ssd1306_over=!ssd1306_over;}
	
void ssd1306_gotoxy(unsigned char x, unsigned char y)
{	
	ssd1306_command(0xB0+y); // Start Page address
	unsigned char col = x/8;
	ssd1306_command(ssd1306_offset+(8*col&0x0F));
	ssd1306_command(0x10+((8*col>>4)&0x0F));
}

void ssd1306_put_i(unsigned int value)
{
	char buffer[10];
	itoa(value,buffer,10);
	ssd1306_string(buffer);
}
void ssd1306_put_l(unsigned long int value)
{
	char buffer[10];
	ltoa(value,buffer,10);
	ssd1306_string(buffer);
}
void ssd1306_put_p(const prog_char *progmem_s)
{
	register char c;
	while ( (c = pgm_read_byte(progmem_s++)) )  ssd1306_char(c);
}
void ssd1306_icon(int icon)
{
	for (int index = 0; index < 12; index++)
	{
		unsigned char ascii = 0;
		if(icon!=255) ascii = (unsigned char)pgm_read_byte(&ICONS[icon][index]);
		if(ssd1306_inv) ascii = 255-ascii;
		ascii = ascii | (1<<7)*(ssd1306_under==true) | (ssd1306_over==true);
		ssd1306_data(ascii);
	}
	ssd1306_data(255*(ssd1306_inv==true)  | (1<<7)*(ssd1306_under==true) | (ssd1306_over==true) );
}

void logo()
{
	for(int i = 0;i<5;i++)
	{
		ssd1306_gotoxy(25,i);
		
		for(int j = 0; j<74; j++)
		{
			unsigned char D = (unsigned char)pgm_read_byte(&LOGO[i*74+j]);
			ssd1306_data(D);
		}
	}
}

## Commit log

2022-01-27 PCB initial
    [SDisk2_REV.csv, SDisk2_REV.kicad_pcb, SDisk2_REV.kicad_sch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]
2022-03-02 Simple SDISK II
    [SDisk2_REV.csv, SDisk2_REV.kicad_pcb, SDisk2_REV.kicad_sch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]

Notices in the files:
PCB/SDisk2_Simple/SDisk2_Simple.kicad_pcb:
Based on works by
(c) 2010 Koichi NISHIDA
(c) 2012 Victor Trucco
